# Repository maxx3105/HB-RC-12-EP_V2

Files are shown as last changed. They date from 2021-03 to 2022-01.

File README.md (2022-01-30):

# HB-RC-12-EP_V2
12 Tasten Fernbedienung mit E-Paper Display für Homematic

Zusätzlich die Option das E-Paper Display direkt anzuschließen und LiPo Akku per QI Ladefunktion aufzuladen.

Dieses Projekt basiert auf der Arbeit von [pa-pa](https://github.com/pa-pa/AskSinPP) ,[Jérôme](https://github.com/jp112sdl/HB-RC-4-Dis-TH) und [MajorTom](https://github.com/TomMajor/SmartHome/tree/master/PCB/HB-RC-12-EP).

# Hardware

### Bauteile

Bauteile                   | Bezeichnung          | Anzahl | Kommentar        | Quelle   |
-------------------------- | -------------------- | ------ | ---------------- | -------- |
C1,C2,C14,C15,C16,C17      | 100nF, 10%, 50V      |   6    |  X7R-G0805 100N  |Reichelt  |
C18                        | 100µF/10V            |   1    | TAJ 3528 100/10  |Reichelt  |
D1                         | LED rot 12 mcd 160°  |   1    | OSO LHR974       |Reichelt  |
D2                         | LED grün 7.1 mcd 160°|   1    | OSO LGR971       |Reichelt  |
R1, R2                     | 1,5K Ohm             |   2    | RND 0805 1 1,5K  |Reichelt  |
R3                         | 10K Ohm              |   1    | RND 0805 1 10K   |Reichelt  |
U1                         | Atmega 1284P-AU      |   1    | TQFP44           |Reichelt  |
U2                         | CC1101               |   1    | 868Mhz Funkmodul |[eBay](https://www.ebay.de/itm/1-2-5PCS-CC1101-868MHZ-Kabellos-Modul-Long-Distance-Transmission-Antenne-1-8V/322983173720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)|
SW1-13                     | Taster 3x6x2,5mm     |  13    | DTSM-3           |[Aliexpress](https://de.aliexpress.com/item/32672806661.html)|
Q1                         | CSTCE8               |   1    | 8Mhz Resonator   |[Aliexpress](https://de.aliexpress.com/item/32436805954.html?spm=a2g0s.9042311.0.0.27424c4dFOxBvK)|
Q3 Statt Q1                | CSTCC8               |   1    | 8Mhz Resonator   |Reichelt  |

Bauteile ohne Hat          | Bezeichnung          | Anzahl | Kommentar        | Quelle |
-------------------------- | -------------------- | ------ | ---------------- | ------ |
C3-C13                     | 1µF, 10%, 25V        |  11    | KEM X5R0805 1,0U |Reichelt|
D3, D4, D5                 | MBR0530              |   3    | MBR0530T1G ONS   |Reichelt|
C3, ... C13                | 1µF, 10%, 25V        |  11    | KEM X5R0805 1,0U |Reichelt|
R8                         | 100K Ohm             |   1    | RND 0805 1 100K  |Reichelt|
R8-1,R8-2                  | 1,0 Ohm              |   2    | SMD-0805 1,00    |Reichelt|
Q2                         | IRLML 6346           |   1    | IRLML 6346       |Reichelt|
L1                         | Induktivität 68 µH   |   1    | L-1616FPS 68µ    |Reichelt|

Bauteile LiPo              | Bezeichnung          | Anzahl | Kommentar       | Quelle |
-------------------------- | -------------------- | ------ | --------------- | ------ |
C19,C20                    | 10uF, +-20%, 10V     |   2    | KEM X5R0805 10U |Reichelt|
D6                         | LED weiß 520 mcd 120°|   1    | SLO SMD-W0805-0 |Reichelt|
R9                         | 4,7K Ohm             |   1    | RND 0805 1 4,7K |Reichelt|
R10                        | 680 Ohm              |   1    | RND 0805 1 680  |Reichelt|
R11                        | 1K Ohm               |   1    | RND 0805 1 1,0K |Reichelt|
R13                        | 100K Ohm             |   1    | RND 0805 1 100K |Reichelt|
U3                         | MCP 1700T-3002E      |   1    | MCP 1700T-3002E |Reichelt|
U4                         | MCP 73831T-2ACI      |   1    | MCP 73831T-2ACI |Reichelt|
U5                         | PC357                |   1    | PC 357NJ0000F   |Reichelt|

#### Sonstiges

~8,3 cm Draht als Antenne

### Programmieradapter
- 1x ISP (z.B. [diesen hier](https://www.diamex.de/dxshop/USB-ISP-Programmer-fuer-Atmel-AVR-Rev2))

# Software

### Fuses
Ext:  0xFF
High: 0xD2
Low:  0xE2 (0xFF für Externen Takt)

`C:\Program Files (x86)\Arduino\hardware\tools\avr\bin> .\avrdude -C ..\etc\avrdude.conf -p m1284p -P com7 -c stk500 -U lfuse:w:0xE2:m -U hfuse:w:0xD2:m -U efuse:w:0xFF:m`

### Firmware

Projektverzeichnis: [HB-RC-12-EP](https://github.com/jp112sdl/HB-RC-12-EP)

Benötigt werden die Bibliotheken
  - [AskSinPP](https://github.com/pa-pa/AskSinPP) (master-Branch verwenden!)
  - [Low-Power](https://github.com/rocketscream/Low-Power)
  - [EnableInterrupt](https://github.com/GreyGnome/EnableInterrupt)
  - [GxEPD](https://github.com/ZinggJM/GxEPD) 
  - [Adafruit-GFX](https://github.com/adafruit/Adafruit-GFX-Library)
  - [Adafruit-BusIO](https://github.com/adafruit/Adafruit_BusIO)
  - [U8g2_for_Adafruit_GFX](https://github.com/olikraus/U8g2_for_Adafruit_GFX)

# Bauanleitung

https://cdn.thingiverse.com/assets/88/70/7e/3d/6d/Aufbauanleitung_YA_HB-RC-12-EP_Case.pdf

# Bilder
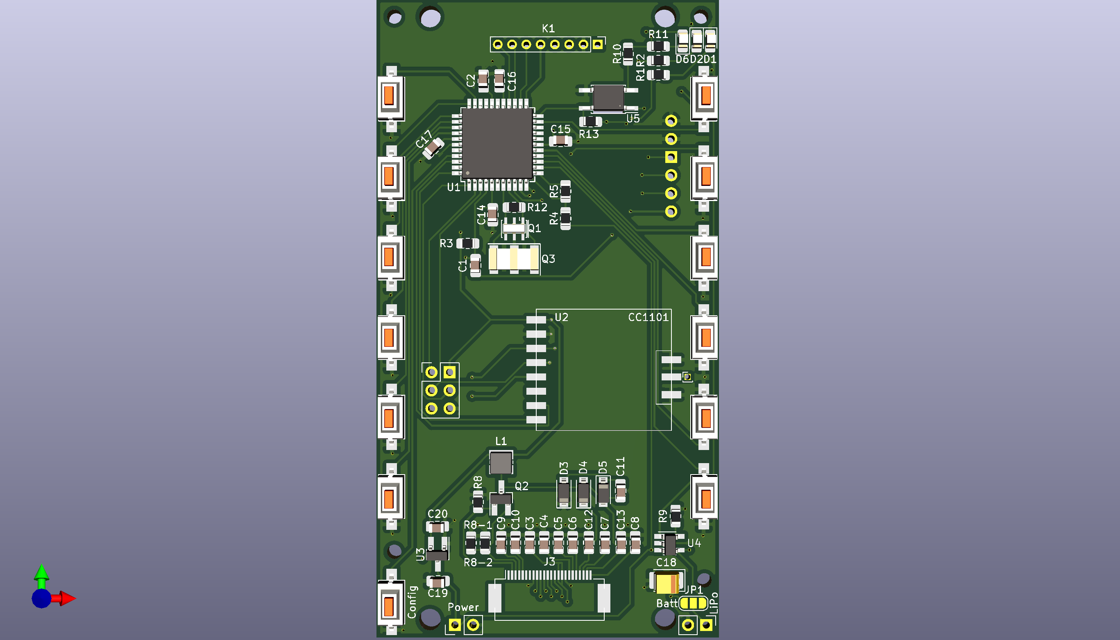
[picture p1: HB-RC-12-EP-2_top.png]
Vorderseite

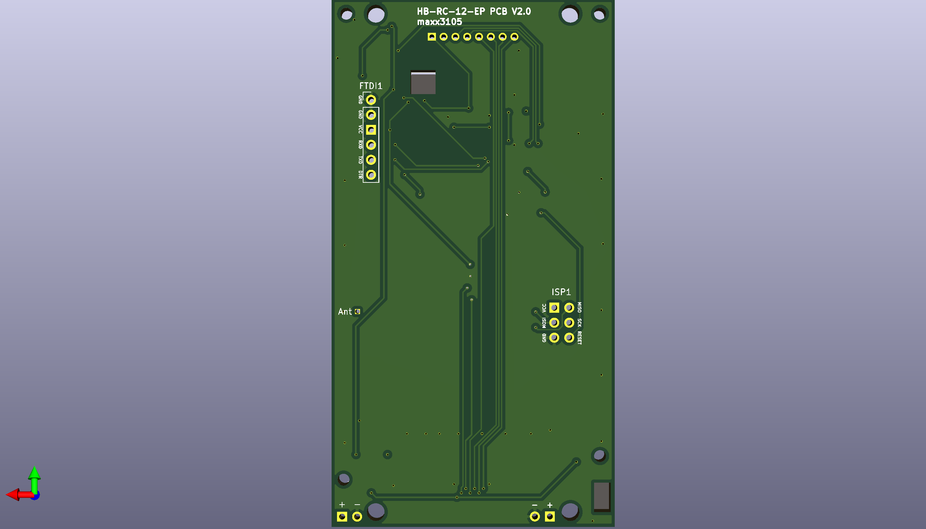
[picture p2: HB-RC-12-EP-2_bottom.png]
Rückseite


# Links
https://homematic-forum.de/forum/viewtopic.php?f=76&t=50160

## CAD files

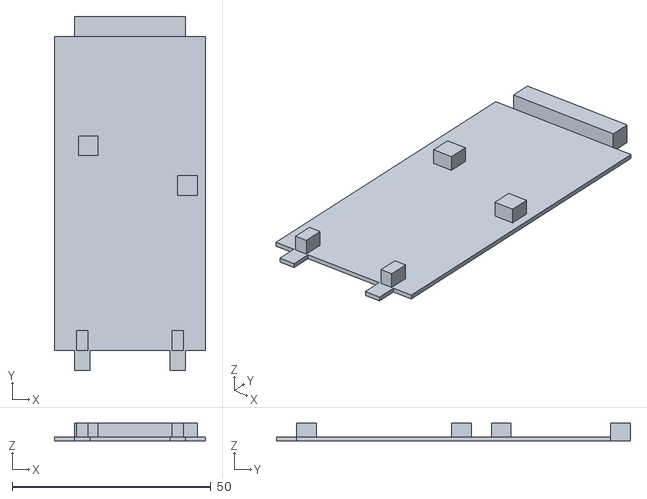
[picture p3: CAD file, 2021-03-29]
HB-RC-12-EP_Spacer.stl
38.0 x 89.0 x 4.50

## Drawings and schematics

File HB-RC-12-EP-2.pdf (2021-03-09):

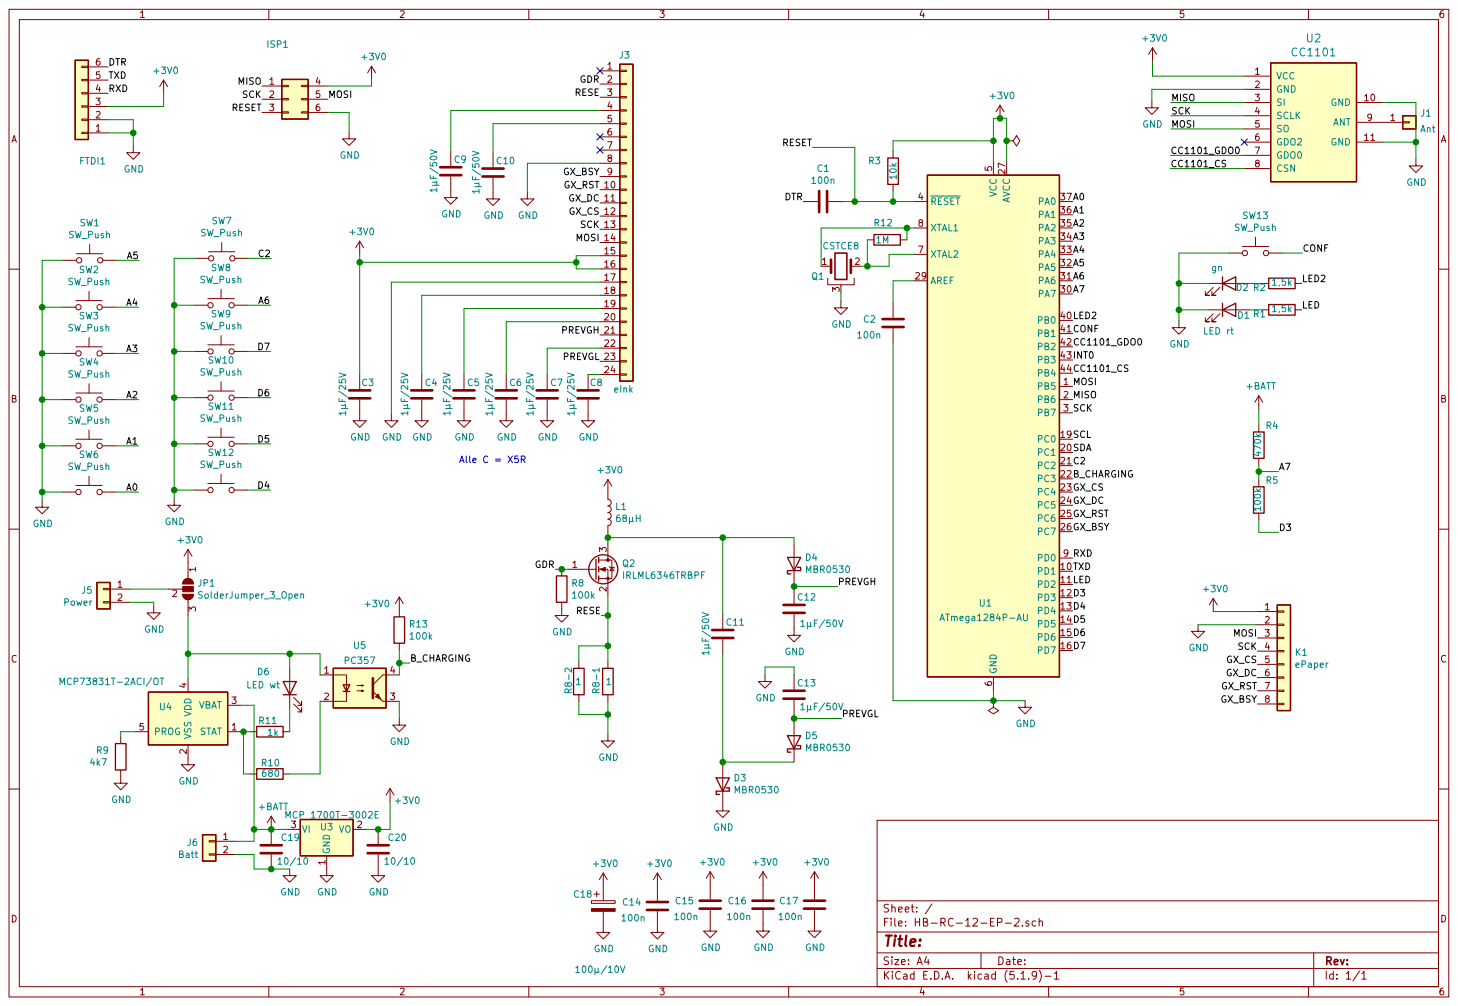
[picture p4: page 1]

Id: 1/1 Title: File: HB-RC-12-EP-2.sch Sheet: / C16

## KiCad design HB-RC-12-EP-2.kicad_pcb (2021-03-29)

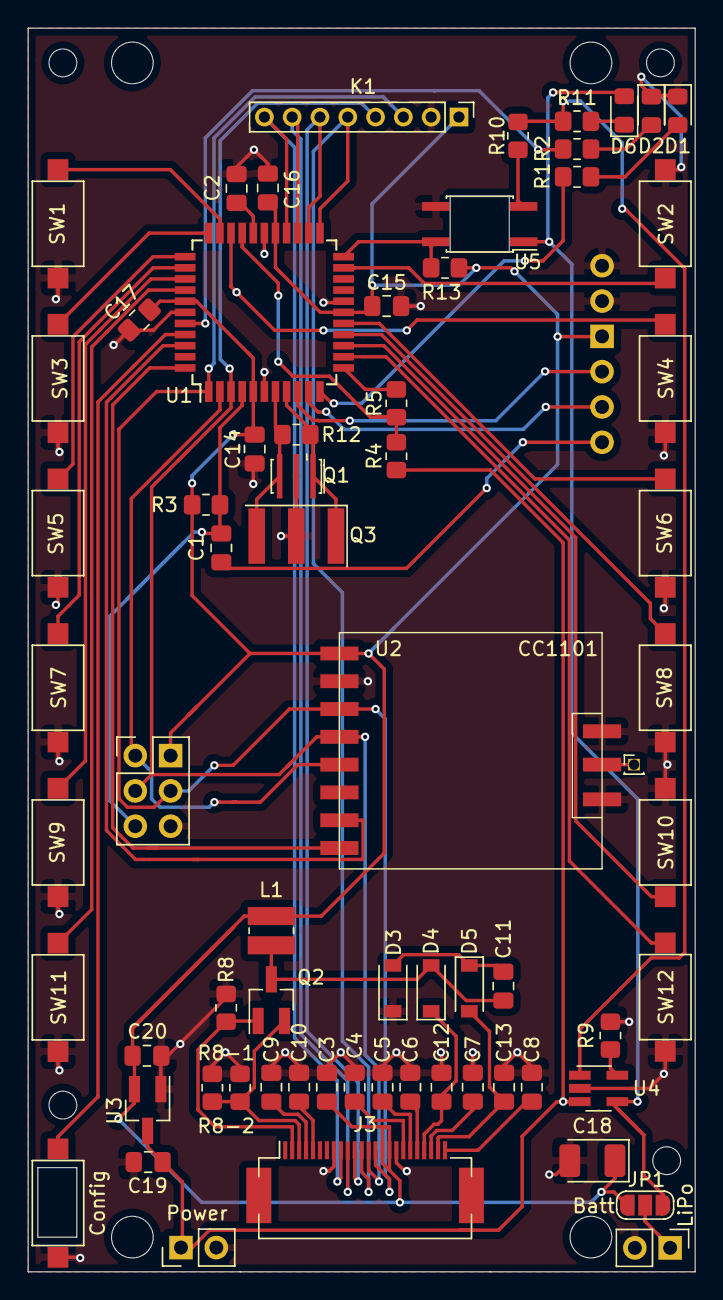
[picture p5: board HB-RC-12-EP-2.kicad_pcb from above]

Board: 2 copper layers, 48.0 x 89.5 mm, 69 parts (1 on the bottom side), 59 nets.

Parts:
+: Power; PinHeader_1x02_P2.54mm_Vertical
Ant: Ant; PinHeader_1x01_P1.00mm_Vertical
C1, C2, C14, C15, C16, C17: 100n; C_0805_2012Metric_Pad1.18x1.45mm_HandSolder
C3, C4, C5, C6, C7, C8: 1µF/25V; C_0805_2012Metric_Pad1.18x1.45mm_HandSolder
C9, C10, C11, C12, C13: 1µF/50V; C_0805_2012Metric_Pad1.18x1.45mm_HandSolder
C18: 100µ/10V; CP_EIA-3528-21_Kemet-B_Pad1.50x2.35mm_HandSolder
C19, C20: 10/10; C_0805_2012Metric_Pad1.18x1.45mm_HandSolder
Config: SW_Push; SW_SPST_CK_RS282G05A3
D1: LED rt; LED_0805_2012Metric_Pad1.15x1.40mm_HandSolder
D2: gn; LED_0805_2012Metric_Pad1.15x1.40mm_HandSolder
D3, D4, D5: MBR0530; D_SOD-123
D6: LED wt; LED_0805_2012Metric_Pad1.15x1.40mm_HandSolder
FTDI1: FTDI; PinHeader_1x06_P2.54mm_Vertical
ISP1: ISP; PinHeader_2x03_P2.54mm_Vertical
J3: eInk; Hirose_FH12-24S-0.5SH_1x24-1MP_P0.50mm_Horizontal
JP1: SolderJumper_3_Open; SolderJumper-3_P1.3mm_Open_RoundedPad1.0x1.5mm_NumberLabels
K1: ePaper; PinHeader_1x08_P2.00mm_Vertical
L1: 68µH; L_Wuerth_MAPI-3012
Power: Batt; PinHeader_1x02_P2.54mm_Vertical
Q1: CSTCE8; Resonator_SMD_muRata_CSTxExxV-3Pin_3.0x1.1mm_HandSoldering
Q2: IRLML6346TRBPF; SOT-23_Handsoldering
Q3: CSTCC8; Resonator_SMD_muRata_SFECV-3Pin_6.9x2.9mm
R1, R2: 1,5k; R_0805_2012Metric_Pad1.20x1.40mm_HandSolder
R3: 10k; R_0805_2012Metric_Pad1.20x1.40mm_HandSolder
R4: 470k; R_0805_2012Metric_Pad1.20x1.40mm_HandSolder
R5, R8, R13: 100k; R_0805_2012Metric_Pad1.20x1.40mm_HandSolder
R8-1, R8-2: 1; R_0805_2012Metric_Pad1.20x1.40mm_HandSolder
R9: 4k7; R_0805_2012Metric_Pad1.20x1.40mm_HandSolder
R10: 680; R_0805_2012Metric_Pad1.20x1.40mm_HandSolder
R11: 1k; R_0805_2012Metric_Pad1.20x1.40mm_HandSolder
R12: 1M; R_0805_2012Metric_Pad1.20x1.40mm_HandSolder
SW1, SW2, SW3, SW4, SW5, SW6, SW7, SW8, SW9, SW10, SW11, SW12: SW_Push; SW_SPST_CK_RS282G05A3
U1: ATmega1284P-AU; TQFP-44_10x10mm_P0.8mm
U2: CC1101; CC1101_SMD
U3: MCP 1700T-3002E; SOT-23_Handsoldering
U4: MCP73831T-2ACI/OT; SOT-23-5_HandSoldering
U5: PC357; SO-4_4.4x3.6mm_P2.54mm

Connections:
+3V0: C3.1, C14.1, C15.1, C16.1, C17.1, C18.1, C20.1, FTDI1.3, ISP1.2, J3.15, J3.16, JP1.1, K1.1, L1.1, R3.1, R13.1, U1.5, U1.17, U1.27, U1.38, U2.1, U3.2
+BATT: C19.1, Power.1, R4.1, U3.3, U4.3
/A0: SW11.2, U1.37
/A1: SW9.2, U1.36
/A2: SW7.2, U1.35
/A3: SW5.2, U1.34
/A4: SW3.2, U1.33
/A5: SW1.2, U1.32
/A6: SW4.2, U1.31
/A7: R4.2, R5.1, U1.30
/B_CHARGING: R13.2, U1.22, U5.4
/C2: SW2.2, U1.21
/CC1101_CS: U1.44, U2.8
/CC1101_GDO0: U1.42, U2.7
/CONF: Config.2, U1.41
/D3: R5.2, U1.12
/D4: SW12.2, U1.13
/D5: SW10.2, U1.14
/D6: SW8.2, U1.15
/D7: SW6.2, U1.16
/DTR: C1.2, FTDI1.6
/GDR: J3.2, Q2.1, R8.1
/GX_BSY: J3.9, K1.8, U1.26
/GX_CS: J3.12, K1.5, U1.23
/GX_DC: J3.11, K1.6, U1.24
/GX_RST: J3.10, K1.7, U1.25
/LED: R1.1, U1.11
/LED2: R2.1, U1.40
/MISO: ISP1.1, U1.2, U2.5
/MOSI: ISP1.4, J3.14, K1.3, U1.1, U2.3
/PREVGH: C12.1, D4.1, J3.21
/PREVGL: C13.2, D5.2, J3.23
/RESE: J3.3, Q2.2, R8-1.1, R8-2.1
/RESET: C1.1, ISP1.5, R3.2, U1.4
/RXD: FTDI1.4, U1.9
/SCK: ISP1.3, J3.13, K1.4, U1.3, U2.4
/TXD: FTDI1.5, U1.10
GND: +.2, C2.2, C3.2, C4.2, C5.2, C6.2, C7.2, C8.2, C9.2, C10.2, C12.2, C13.1, C14.2, C15.2, C16.2, C17.2, C18.2, C19.2, C20.2, Config.1, D1.1, D2.1, D3.1, FTDI1.1, FTDI1.2, ISP1.6, J3.8, J3.17, K1.2, Power.2, Q1.2, Q3.2, R8.2, R8-1.2, R8-2.2, R9.2, SW1.1, SW2.1, SW3.1, SW4.1, SW5.1, SW6.1, SW7.1, SW8.1, SW9.1, SW10.1, SW11.1, SW12.1, U1.6, U1.18, U1.28, U1.39, U2.2, U2.10, U2.11, U3.1, U4.2, U5.3
unnamed: C2.1, U1.29
unnamed: C4.1, J3.18
unnamed: C5.1, J3.19
unnamed: C6.1, J3.20
unnamed: C7.1, J3.22
unnamed: C8.1, J3.24
unnamed: C9.1, J3.4
unnamed: C10.1, J3.5
unnamed: C11.1, D4.2, L1.2, Q2.3
unnamed: C11.2, D3.2, D5.1
unnamed: D1.2, R1.2
unnamed: D2.2, R2.2
unnamed: D6.1, R11.2
unnamed: D6.2, JP1.3, U4.4, U5.1
unnamed: Ant.1, U2.9
unnamed: +.1, JP1.2
unnamed: Q1.1, Q3.1, R12.1, U1.8
unnamed: Q1.3, Q3.3, R12.2, U1.7
unnamed: R9.1, U4.5
unnamed: R10.1, R11.1, U4.1
unnamed: R10.2, U5.2

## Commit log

2021-03-10 Add files via upload
    Bugfix
    [HB-RC-12-EP-2-B_Cu.gbr, HB-RC-12-EP-2-B_Mask.gbr, HB-RC-12-EP-2-B_Paste.gbr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]
2021-03-13 Add files via upload
    Change some footprints to handsolder. Add CSTCE.
    [HB-RC-12-EP-2-B_Cu.gbr, HB-RC-12-EP-2-B_Mask.gbr, HB-RC-12-EP-2-B_Paste.gbr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]
